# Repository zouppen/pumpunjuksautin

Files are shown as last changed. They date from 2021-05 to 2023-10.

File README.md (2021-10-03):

# Pumpunjuksautin - Defrauding heat pumps for fun and profit

## Introduction
Pumpunjuksautin is a device for introducing a measure of load control into
heating systems where no external control features such as automation buses
exist. The core idea is to modify the signal the heating controller gets from
the thermistor measuring it's warm water accumulator temperature. By modifying
this signal so that the accumulator seems warmer than it is in actuality, the
heating can be impeded until the desired time.

In practice, Pumpunjuksautin is meant to be attached to Modbus RTU bus, through
which it is controlled by building automation. Typically the heating duty cycle
is delayed until either energy market or solar power generation allow for cost
efficient heating.

## Repository content
This repository contains the design of the whole Pumpunjuksautin device,
divided to it's components:
* [Firmware source code](avr/)
* [Documentation](docs/)
* [Enclosure design](enclosure/README.md)
* [Printed circuit board design](pcb/)
* [Operational utilities](juksutil/) (JuksUtil)

## License
The contents of this repository are licensed under the GNU General Public
License version 3 or later. See file LICENSE for the license text.

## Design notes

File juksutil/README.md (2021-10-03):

# JuksUtil

Utility for communicating with JuksOS devices, including
Pumpunjuksautin. Supports both ASCII and Modbus protocols.

## Compiling

Requires a C compiler, libmodbus and glib libraries and CMake to build. In Debian
and Ubuntu, you can install the requirements with:

```sh
sudo apt install cmake libmodbus-dev libglib2.0-dev
```

To build:

```sh
mkdir build
cd build
cmake ..
make
```

## Summary of commands

In principle, if when using ASCII interface, you must supply device
path with `-d`. With Modbus, you additionally need server id (better
known as slave id) with `-s`.

Time zone related commands such as `show-transition` and `sync-time`
accept `-z` parameter for supplying the desired time zone.

Help is available with `juksutil --help`.

### show-transition

Show current time zone and future DST transition, if any. Doesn't need
any device. It just shows what would be written. Also, it's
suprisingly useful tool to check DST changes overall, in case you are
interested about time zone stuff like me.

<pre>
$ juksutil show-transition
Current and following time zone for <strong>Europe/Berlin</strong>:

                  <strong>UTC time             Local time           Zone   UNIX time  UTC off
Current time:</strong>     2021-10-03 18:59:09  2021-10-03 20:59:09  +0200  1633287549   +7200
<strong>Next transition:</strong>  2021-10-31 01:00:00  2021-10-31 02:00:00  +0100  1635642000   +3600

That is, on October 31 when the time gets 03:00, the hands are moved to 02:00.
</pre>

### get-time

Get current time from the device. Format is ISO 8601 timestamp with
time zone. It shows the current time and time zone the device is
observing.

### sync-time

Synchronize clock of JuksOS device. Sets also DST transition
table. Supply the desired time zone with `-z` or otherwise your
computer zone is used.

The command outputs nothing on success. To verify it, you may run
`juksutil get-time`.

### send

Read and/or write values from/to the hardware via ASCII
interface. This requires that the device firmware is built with ASCII
interface (CMake variable `-D WITH_ASCII=ON`).

The format is: `send KEY[=VALUE]..`, example: `juksutil send version led=1`.

The supported commands are described in [commands.tsv](../avr/commands.tsv).

## How about supporting the remaining Modbus commands?

Not all Modbus commands are supported because there is better tools for
doing the stuff which are not timing critical like setting clock
time. One of them is a nice command-line utility called
[modbus-cli](https://github.com/favalex/modbus-cli).

Modbus register chart is available in [commands.tsv](../avr/commands.tsv).

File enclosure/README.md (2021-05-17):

# Enclosure

Enclosure for Pumpunjuksautin. Designed for DIN rail attachment

## Copyright

PCB mounting clip for 35mm DIN Rail (file din_clip_01.dxf) by
RobertHuntis licensed under the Creative Commons - Attribution
license. Fetched from https://www.thingiverse.com/thing:101024

Rest is work by Joel Lehtonen.

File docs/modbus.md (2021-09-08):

# Modbus register table

**THIS IS A DRAFT!**

## Coils

Coils are read-write.

|  Address | False | True | Description |
|---:|---|---|---|
| `0x0001` | LED off | LED on | Indicator LED control (for testing comms) |

## Input bits

Every input is read-only.

|  Address | False | True | Description |
|---:|---|---|---|
| `0x0001` | LED off | LED on | Heat pump error LED status |
| `0x0002` | Clock unset | Clock set | Internal real-time clock status |

## Holding registers

A single register is 16-bit value. All values spanning multiple
registers have big-endian byte order.

| Address | Size | Read | Write | Data type | Unit | Description |
|---|-----:|:----:|:-----:|---|---|---|
| TBD | 16 | X | | char[32]  | | Firmware version string, NUL padded |
| TBD | 2 | X | X | uint32 | unix | Current system time |
| TBD | 2 | X | X | int32 | gmtoff | Current UTC offset |
| TBD | 2 | X | X | uint32 | unix | Time of next UTC offset change. 0 if not set. |
| TBD | 2 | X | X | int32 | gmtoff | Next UTC offset |
| TBD | 1 | X | | int16 | 0.01°C | Heat pump temperature (K9 thermistor line) |
| TBD | 1 | X | | int16 | 0.01°C | Tank temperature (K5 thermistor line) |
| TBD | 1 | X | | int16 | 0.01°C | Outside temperature |
| TBD | 1 | X | X | int16 | mV | Juksautus target voltage |
| TBD | 1 | X | | int16 | mV | Juksautus measured voltage |

## Legend

* **size**: Data length in number of registers (`nb` in libmodbus)
* **unix**: Number of seconds since UNIX epoch
* **gmtoff**: UTC offset in seconds

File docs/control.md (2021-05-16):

# How Pumpunjuksautin works

Pulls voltage over NTC thermistor while recovering original thermistor
resistance.

The firmware has bookkeeping about the duty cycle. For example if the
*DRIVE* is in LOW state for 10 ms and in HI-Z state for 90 ms, the duty
cycle D is 0.9.

Fill in parameters in this formula from the circuit below:



Variables in the formula

This allows us to fake a higher temperature reading and at the same time
do measurements. All this without disconnecting the thermistor from the
circuit.

## Is it possible to fake lower temperatures, too?

Yes, but the formulas aren't derived yet... We can put *DRIVE* to 5
volts and observe the duty cycle.

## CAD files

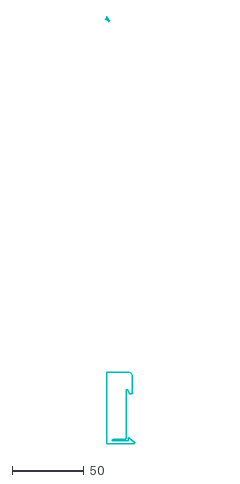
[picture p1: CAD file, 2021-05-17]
enclosure/din_clip_01.dxf
20.4 x 298.3

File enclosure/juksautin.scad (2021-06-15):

open = true;
//open = false;

module screwdriver_hole(width, length, depth) {
    linear_extrude(depth) {
        // The screwdriver opening
        hull() {
            for (pos = [-length/2, length/2]) {
                translate([pos,0,0]) circle(width/2, $fn=6);
            }
        }
    }
}

// Din rail clamp
difference() {
    pos_x = pcb_width/2-19;
    pos_y = h+2;
    linear_extrude(inner_height+2) translate([pos_x,pos_y,0]) rotate([180,0,90]) import("din_clip_01.dxf");
    translate([pos_x,pos_y+12.6,inner_height/2+1]) rotate([0,90,0]) screwdriver_hole(2, 5, 3);
}

translate([2+margin/2,2+margin/2 + (open ? -60 : 0),pcb+pcb_surface]) {
    // Kicad model via Blender
    rotate([90,0,0]) translate([0,0,0]) import("pcb.stl");
}

module pcb_box(w, h, pcb_thickness, above, below, rail=3, wall=2) {
    inside_h = above+below+pcb_thickness;
    difference () {
        // Outer wall
        cube([w+2*wall, h+2*wall, inside_h+2*wall]);
        // Inner wall
        translate([wall+rail,0,wall]) {
            cube([w-2*rail, h+wall, inside_h]);
        }
        // Rail
        translate([wall,wall-1,wall+below]) {
            cube([w,h+1, pcb_thickness]);
        }
        // Front opening
        translate([wall,0,wall]) {
            cube([w,wall,inside_h]);
        }
        
        // Half a wall from the front. +1 offset to avoid UI bug.
        translate([-1,-1,-1]) cube([w+2*wall+2,wall/2+1,inside_h+2*wall+2]);
        
        dent_depth=3;
        translate([wall,2*wall, wall+below+pcb_thickness-margin]) {
            cube([w,dent_depth,above+margin]);
        }
    }
}

module mc(x,z,terminals=9, pitch=3.81) {
    translate([x-margin/2,-1,z-margin/2]) cube([5.2+(terminals-1)*pitch+margin,4,7.25+margin]);
}

margin = 0.4;
pcb = 1.6;
pcb_real = 2.2;
pcb_width = 65+margin;
h = 35+margin;
pcb_surface = 3.5;
pull = 3;

thick = 2+1.2; // Thickness of front panel

module clip() {
    clip_start = 4.4;
    clip_x = 1.5;
    clip_y = 3.9;
    clip_w = 2.4;
    clip_h = 7;
    clip_z = 7.85;
    translate([0,0,clip_z]) linear_extrude(clip_h) polygon([[0,0],[clip_w,0],[clip_w,clip_start+clip_y],[-clip_x,clip_start],[0,clip_start]]);
}

above=12;

// PCB box
pcb_box(pcb_width, h, pcb_real, above-pcb+margin, pcb_surface-pcb, rail=1.5);

// Calculated from magic values
inner_height = pcb_real+ above-pcb+margin+pcb_surface-pcb+2;

translate([open ? 80 : 0,0,0]) with_idc_frame([49.25,0,pcb_surface+0.8],8) {
    difference () {
        union () {
            // Outer cover
            cube([pcb_width+4,1,inner_height+2]);

            // Indent
            translate([2+margin/2,1,2+margin/2]) {
                cube([pcb_width-margin,1,inner_height-margin-2]);
            }
            
            // Clips
            translate([4-0.2,0,0]) clip();
            translate([pcb_width+0.2,0,0]) mirror([1,0,0]) clip();

        }
        
        mc(8.1,pcb_surface+2.4);
    }
}

module with_idc_frame(pos=[0,0,0], depth=5) {
    module obj(tweak=0) {
        translate(pos) rotate([90,0,0]) translate([0,-20,-depth-tweak]) linear_extrude(depth+2*tweak) children();
    }
    
    difference() {
        children();
        obj(0.1) import("idc-inner.svg");
    }
    obj() import("idc-outer.svg");
}

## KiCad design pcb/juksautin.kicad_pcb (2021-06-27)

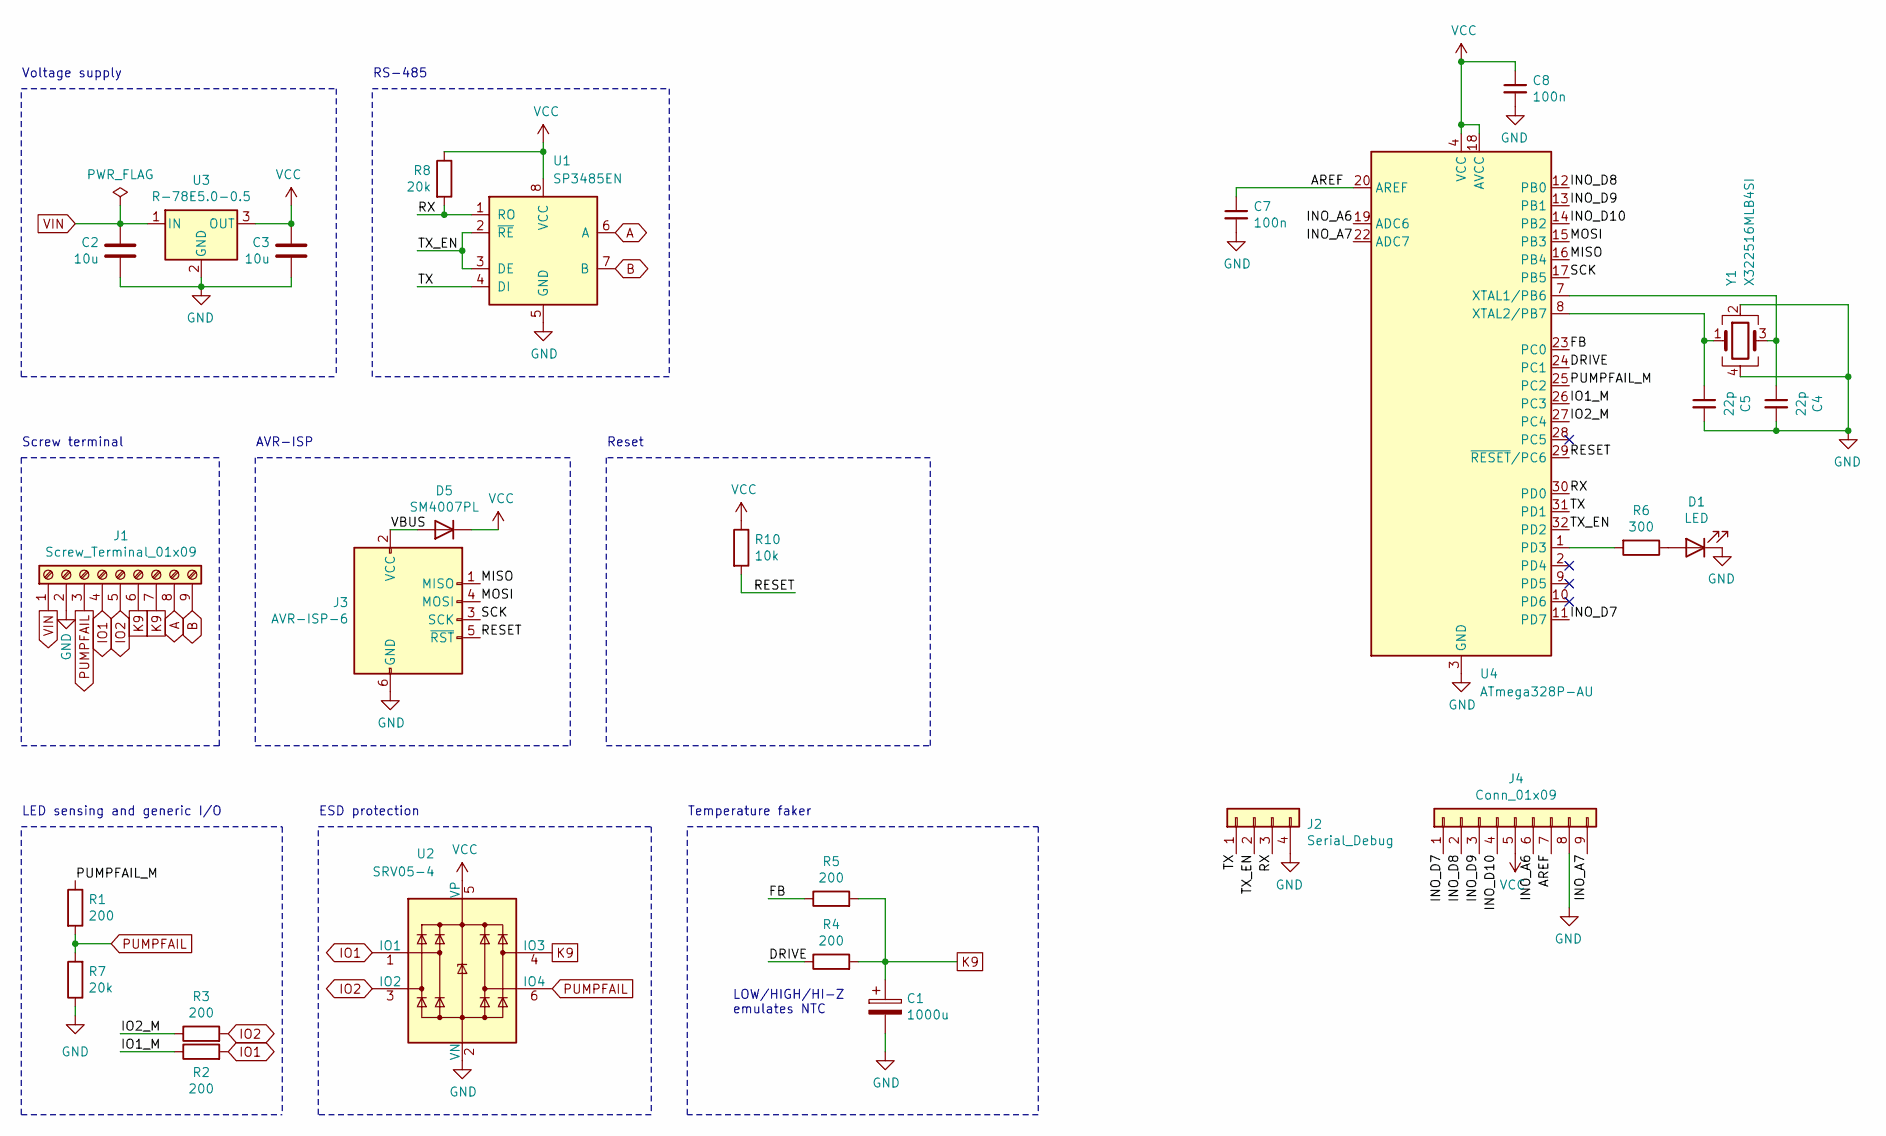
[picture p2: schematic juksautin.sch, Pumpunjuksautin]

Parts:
C1: 1000u; CP_Elec_8x10; LCSC C134755
C2, C3: 10u; C_1206_3216Metric; LCSC C13585
C4, C5: 22p; C_0402_1005Metric; LCSC C1555
C7, C8: 100n; C_0402_1005Metric; LCSC C1525
D1: LED; LED_0603_1608Metric; LCSC C72043
D5: SM4007PL; D_SOD-123F; LCSC C64898
J1: Screw_Terminal_01x09; PhoenixContact_MC_1,5_9-G-3.81_1x09_P3.81mm_Horizontal
J2: Serial_Debug; PinHeader_1x04_P1.27mm_Vertical
J3: AVR-ISP-6; PinHeader_2x03_P2.54mm_Horizontal
J4: Conn_01x09; PinHeader_1x09_P2.54mm_Vertical
R1, R2, R3, R4, R5: 200; R_0603_1608Metric; LCSC C8218
R6: 300; R_0603_1608Metric; LCSC C23025
R7, R8: 20k; R_0603_1608Metric; LCSC C4184
R10: 10k; R_0603_1608Metric; LCSC C25804
U1: SP3485EN; SOIC-8_3.9x4.9mm_P1.27mm; LCSC C8963
U2: SRV05-4; SOT-23-6; LCSC C85364
U3: R-78E5.0-0.5; Converter_DCDC_RECOM_R-78E-0.5_THT
U4: ATmega328P-AU; TQFP-32_7x7mm_P0.8mm
Y1: X322516MLB4SI; Crystal_SMD_3225-4Pin_3.2x2.5mm

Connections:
/AREF: C7.1, J4.7, U4.20 (AREF)
/DRIVE: R4.1, U4.24 (PC1)
/FB: R5.1, U4.23 (PC0)
/INO_A6: J4.6, U4.19 (ADC6)
/INO_A7: J4.9, U4.22 (ADC7)
/INO_D7: J4.1, U4.11 (PD7)
/INO_D8: J4.2, U4.12 (PB0)
/INO_D9: J4.3, U4.13 (PB1)
/INO_D10: J4.4, U4.14 (PB2)
/IO1_M: R2.1, U4.26 (PC3)
/IO2_M: R3.1, U4.27 (PC4)
/MISO: J3.1 (MISO), U4.16 (PB4)
/MOSI: J3.4 (MOSI), U4.15 (PB3)
/PUMPFAIL_M: R1.1, U4.25 (PC2)
/RESET: J3.5 (~RST), R10.2, U4.29 (~RESET~/PC6)
/RX: J2.3, R8.2, U1.1 (RO), U4.30 (PD0)
/SCK: J3.3 (SCK), U4.17 (PB5)
/TX: J2.1, U1.4 (DI), U4.31 (PD1)
/TX_EN: J2.2, U1.2 (~RE~), U1.3 (DE), U4.32 (PD2)
/VBUS: D5.2 (A), J3.2 (VCC)
A: J1.8, U1.6 (A)
B: J1.9, U1.7 (B)
GND: C1.2, C2.2, C3.2, C4.2, C5.2, C7.2, C8.2, D1.1 (K), J1.2, J2.4, J3.6 (GND), J4.8, R7.1, U1.5 (GND), U2.2 (VN), U3.2 (GND), U4.3 (GND), U4.5 (GND), U4.21 (GND), Y1.2, Y1.4
IO1: J1.4, R2.2, U2.1 (IO1)
IO2: J1.5, R3.2, U2.3 (IO2)
K9: C1.1, J1.6, J1.7, R4.2, R5.2, U2.4 (IO3)
unnamed: C4.1, U4.7 (XTAL1/PB6), Y1.3
unnamed: C5.1, U4.8 (XTAL2/PB7), Y1.1
unnamed: D1.2 (A), R6.1
unnamed: R6.2, U4.1 (PD3)
PUMPFAIL: J1.3, R1.2, R7.2, U2.6 (IO4)
VCC: C3.1, C8.1, D5.1 (K), J4.5, R8.1, R10.1, U1.8 (VCC), U2.5 (VP), U3.3 (OUT), U4.4 (VCC), U4.6 (VCC), U4.18 (AVCC)
VIN: C2.1, J1.1, U3.1 (IN)

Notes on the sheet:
LOW/HIGH/HI-Z emulates NTC
LED sensing and generic I/O
Temperature faker
Screw terminal
RS-485
Voltage supply
ESD protection
AVR-ISP
Reset

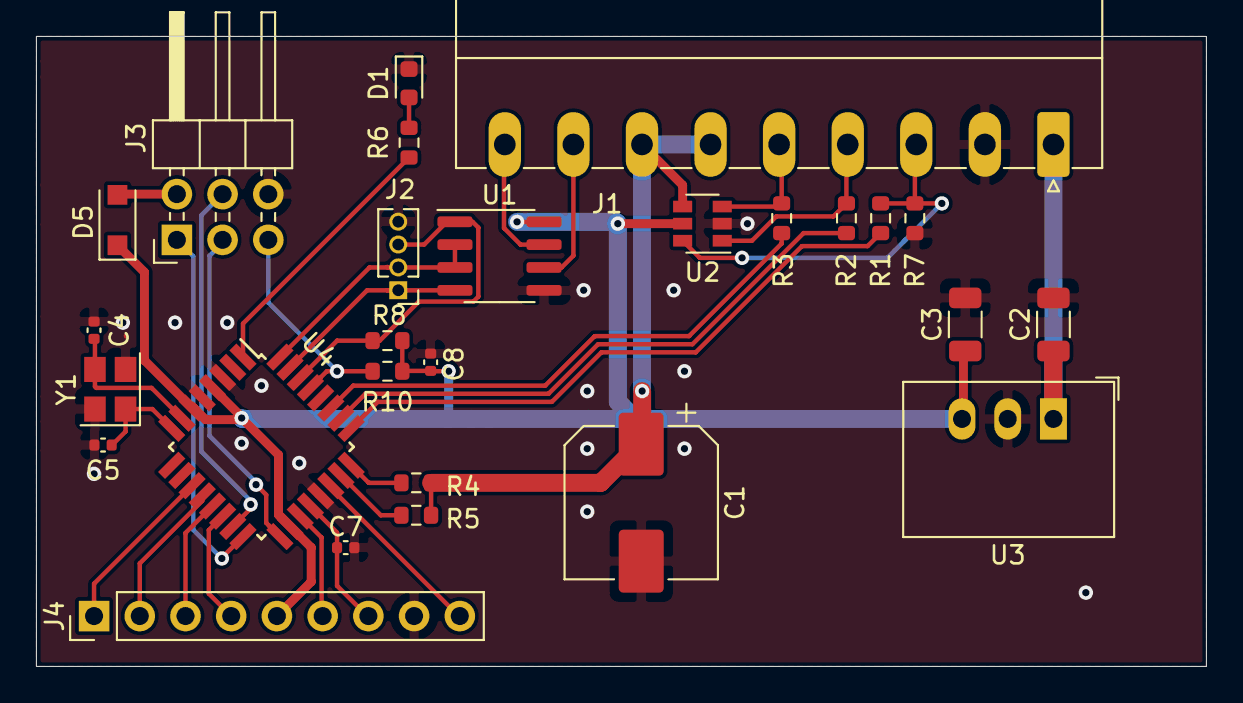
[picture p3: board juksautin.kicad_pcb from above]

Board: 2 copper layers, 65.0 x 35.0 mm, 27 parts (0 on the bottom side), 33 nets.

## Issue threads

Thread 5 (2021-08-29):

ASCII protocol

zouppen, 2021-08-29:
Implement serial line protocol in plain ASCII which doesn't clash with Modbus #16 so in theory they could be simultaneously enabled. This makes controlling the device easier with plain socat.

zouppen, 2021-09-11:
I consider the protocol done. It doesn't yet have so many commands but the architecture is proven so the rest is just adding more and more commands,

Closed 2021-09-11.

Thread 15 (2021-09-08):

Output gets sometimes trucated in process_write() in interface_ascii.c

zouppen, 2021-09-08:
Currently using format string `%1s` instead of `%s` because for some reason the output is truncated with input of
"`WRITE`". Doesn't happen with "`WRITE `". This might be avr-libc bug or a memory leak in our code.

Doesn't help if using SRAM strings instead of PROGMEM.

zouppen, 2021-09-08:
NULL pointer was printed with %s which caused the formatting issue. Checking NULL condition before calling the function.

Closed 2021-09-08.

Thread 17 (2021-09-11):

Use fixed point where practical

zouppen, 2021-09-11:
Get rid of unnecessary floating point operations both for speed reasons but more importantly for making the control logic more accurate because Modbus #16 anyway will use millivolts in the control

zouppen, 2021-09-20:
Git grep tells me all floating point operations except `juksautin_compute_k5_real_voltage` are removed. That function is not currently called from anywhere. Consider this done.

Closed 2021-09-20.

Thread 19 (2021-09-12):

EEPROM storage

zouppen, 2021-09-12:
Use EEPROM storage for some configuration variables to make them persistent over boot, such as:

- Juksautus target voltage
- Temperature conversion coefficients
- Time zone information

zouppen, 2021-09-20:
This is done, also added fuse change to allow EEPROM to stay intact after firmware updates. There is #22 which will go to EEPROM, too, but it's a separate ticket. Temperature coefficients are different case, too, related to #3. Done.

Closed 2021-09-20.

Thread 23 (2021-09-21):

Clock drift correction

zouppen, 2021-09-21:
There is external and decent 16MHz crystal on board but it could be made more accurate, especially when Juksautin is having constant temperature conditions. It requires three facilities:

* [ ] EEPROM or SRAM storage of last written timestamp
* [ ] Holding register for clock drift (int32)
* [ ] System tick change: Add countdown for the next adjustment
* [ ] Utility for updating the clock while adjusting drift

Low priority. Nice to have.

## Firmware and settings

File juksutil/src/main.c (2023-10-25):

// Main module for JuksUtil
// SPDX-License-Identifier:   GPL-3.0-or-later
// Copyright (C) 2021 Joel Lehtonen
//
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
#define _GNU_SOURCE
#include <stdio.h>
#include <stdlib.h>
#include <unistd.h>
#include <modbus.h>
#include <err.h>
#include <errno.h>
#include <glib.h>
#include <time.h>
#include <inttypes.h>
#include "tz.h"
#include "sync_clock.h"
#include "serial.h"

static time_t get_timestamp(void);
static tzinfo_t get_tzinfo(void);
static char *format_iso8601(time_t ref);
static char *format_localtime(time_t ref, int32_t gmtoff, char *fmt);
static void cmd_show_transition(void);
static void cmd_sync_clock_modbus();
static void cmd_sync_clock_ascii();
static void cmd_get_time_modbus();
static void cmd_get_time_ascii();
static void cmd_ascii(int const argc, char **argv);
static bool matches(char const *const arg, char const *command, bool const cond);
static void serial_timeout(int signo);
static modbus_t *main_modbus_init(void);
static void main_modbus_free(modbus_t *ctx);
static FILE *main_serial_init(void);

static gchar *time_zone = "localtime";
static gchar *now_str = NULL;
static gchar *dev_path = NULL;
static gint dev_baud = 9600;
static gint dev_slave = 0;
static gboolean break_first = false;

static GOptionEntry entries[] =
{
	{ "timezone", 'z', 0, G_OPTION_ARG_STRING, &time_zone, "Time zone used in date operations, e.g. Europe/Berlin. Default: localtime", "TZ"},
	{ "now", 'n', 0, G_OPTION_ARG_STRING, &now_str, "Use this time instead of current time. Any format accepted by `date` is fine. Default: now", "STRING"},
	{ "device", 'd', 0, G_OPTION_ARG_FILENAME, &dev_path, "Device path to JuksOS device", "PATH"},
	{ "baud", 'b', 0, G_OPTION_ARG_INT, &dev_baud, "Device baud rate. Default: 9600", "BAUD"},
	{ "slave", 's', 0, G_OPTION_ARG_INT, &dev_slave, "Device Modbus server id. If not defined, ASCII protocol is used", "ID"},
	{ "break", 'B', 0, G_OPTION_ARG_NONE, &break_first, "Send BREAK before the command. Default: no break", NULL},
	{ NULL }
};

int main(int argc, char **argv)
{
	g_autoptr(GError) error = NULL;
	g_autoptr(GOptionContext) context = g_option_context_new("COMMAND");
	g_option_context_add_main_entries(context, entries, NULL);
	g_option_context_set_summary(context, "Tool for communicating with JuksOS devices such as Pumpunjuksautin.");
	g_option_context_set_description(context,
					 "Commands:\n"
					 "  show-transition       Show current time zone and future DST transition, if any.\n"
					 "  get-time              Get current time from the device.\n"
					 "  sync-time             Synchronize clock of JuksOS device. Sets also DST transition table.\n"
					 "  send KEY[=VALUE]..    Read and/or write values from/to the hardware via ASCII interface\n"
					 "\n"
					 "For more information about accepted timestamp formats, run: info coreutils date input\n"
					 "To get list of all time zones known by your system, run: timedatectl list-timezones\n"
					 "");

	if (!g_option_context_parse(context, &argc, &argv, &error))
	{
		errx(1, "Option parsing failed: %s", error->message);
	}

	// Command validation and selection
	if (argc < 2) {
		errx(1, "Command missing. See %s --help", argv[0]);
	}

	// Set up signal handler for timeouts
	struct sigaction act;
	act.sa_handler = serial_timeout;
	sigemptyset(&act.sa_mask);
	act.sa_flags = 0;
	if (sigaction(SIGALRM, &act, NULL) == -1) {
		err(1, "Unable to set a signal handler");
	}

	// Command parser
	if (matches(argv[1], "show-transition", argc == 2)) {
		// Validate args
		cmd_show_transition();
	} else if (matches(argv[1], "sync-time", argc == 2)) {
		if (dev_slave) {
			cmd_sync_clock_modbus();
		} else {
			cmd_sync_clock_ascii();
		}
	} else if (matches(argv[1], "get-time", argc == 2)) {
		if (dev_slave) {
			cmd_get_time_modbus();
		} else {
			cmd_get_time_ascii();
		}
	} else if (matches(argv[1], "send", argc > 2)) {
		cmd_ascii(argc-2, argv+2);
	} else {
		errx(1, "Invalid command name. See %s --help", argv[0]);
	}
	return 0;
}

static bool matches(char const *const arg, char const *command, bool const cond)
{
	if (strcmp(arg, command)) return false;
	if (!cond) errx(1, "Invalid number of arguments to %s. See --help", command);
	return true;
}

static void cmd_ascii(int const cmds, char **cmd)
{
	if (dev_slave) {
		errx(1, "ASCII interface not available using Modbus. Don't use -s.");
	}
	
	// Craft compound message
	g_autoptr(GString) line_in = g_string_new(cmd[0]);
	for (int i=1; i<cmds; i++) {
		g_string_append_c(line_in, ' ');
		g_string_append(line_in, cmd[i]);
	}
	g_string_append_c(line_in, '\n');

	// Do the serial operations with a timeout
	alarm(1);

	FILE *f = main_serial_init();

	if (fputs(line_in->str, f) == EOF) {
		errx(1, "Unable to write to serial port");
	}

	char *line_out = NULL;
	size_t len = 0;
	if (getline(&line_out, &len, f) == -1) {
		errx(1, "Unable to read from serial port");
	}

	// Cancel timeout
	alarm(0);

	if (line_out[0] == ' ') {
		// Put the command as a reference for the error
		// message.
		fputs(line_in->str, stdout);
	}
	fputs(line_out, stdout);
	free(line_out);
	fclose(f);
}

static void serial_timeout(int signo) {
	errx(1, "ASCII serial protocol timeout. Is the device on and is the baud rate correct?");
}

// Command for getting current time via ASCII
static void cmd_get_time_ascii()
{
	char *s = "now";
	cmd_ascii(1, &s);
}

// Command for getting current time via Modbus
static void cmd_get_time_modbus()
{
	modbus_t *ctx = main_modbus_init();
	
	g_autoptr(GString) s = g_string_new(NULL);
	sync_clock_get_time_modbus(s, ctx);
	puts(s->str);

	main_modbus_free(ctx);
}

// Command for syncing the clock time of a device.
static void cmd_sync_clock_modbus()
{
	modbus_t *ctx = main_modbus_init();
	
	tzinfo_t info = get_tzinfo();
	sync_clock_modbus(&info, now_str == NULL, ctx);

	main_modbus_free(ctx);
}

// Command for syncing the clock time of a device.
static void cmd_sync_clock_ascii()
{
	FILE *f = main_serial_init();

	tzinfo_t info = get_tzinfo();
	sync_clock_ascii(&info, now_str == NULL, f);

	fclose(f);
}

// Command for just showing the next DST transition and the UTC offset
// before and after the transition.
static void cmd_show_transition()
{
	tzinfo_t info = get_tzinfo();
	char *reftime_label = now_str == NULL ?
		"Current time:  ":
		"Reference time:";
	g_autoptr(GString) name = tz_name(time_zone);
	printf("Current and following time zone for \x1b[1m%s\x1b[0m:\n\n", name->str);
	printf("\x1b[1m                  UTC time             Local time           Zone   UNIX time  UTC off\x1b[0m\n");
	printf("\x1b[1m%s\x1b[0m   %-21s%-27s%11ld%+8d\n", reftime_label, format_iso8601(info.ref_time), format_localtime(info.ref_time, info.gmtoff_now, "%F %T  %z"), info.ref_time, info.gmtoff_now);
	if (info.transition) {
		printf("\x1b[1mNext transition:\x1b[0m  %-21s%-27s%11ld%+8d\n", format_iso8601(info.transition), format_localtime(info.transition, info.gmtoff_after, "%F %T  %z"), info.transition, info.gmtoff_after);
		printf("\nThat is, on %s,", format_localtime(info.transition, info.gmtoff_now, "%B %d when the time gets %H:%M"));
		printf(" the hands are moved to %s.\n", format_localtime(info.transition, info.gmtoff_after, "%H:%M"));
	} else {
		printf("\x1b[1mNext transition:\x1b[0m  No future transitions\n");
	}
}

// Returns time formatted to ISO 8601 UTC timestamp. This function is
// not re-entrant. May terminate the program in case of an error.
static char *format_iso8601(time_t ref)
{
	static char buf[25];
	struct tm *tm = gmtime(&ref);
	if (tm == NULL) goto fail;
	if (strftime(buf, sizeof(buf), "%F %T", tm) == 0) goto fail;
	return buf;
 fail:
	errx(1, "Date formatting error");
}

// Returns time formatted to ISO 8601 local time. This function is
// not re-entrant. May terminate the program in case of an error.
static char *format_localtime(time_t ref, int32_t gmtoff, char *fmt)
{
	static char buf[40];
	ref += gmtoff;
	struct tm tm;
	gmtime_r(&ref, &tm);
	tm.tm_gmtoff = gmtoff; // glibc only way to set timezone!
	if (strftime(buf, sizeof(buf), fmt, &tm) == 0) goto fail;
	return buf;
 fail:
	errx(1, "Date formatting error");
}

// Get timestamp from global variable if set or use the current
// time. May terminate the program if invalid time given.
static time_t get_timestamp()
{
	time_t now;

	// Fetching current time
	if (now_str != NULL) {
		// Trying to parse it to UNIX timestamp with
		// `date`. It's better than any libc or glib
		// parsing function.
		g_autoptr(GString) cmd = g_string_new("date +%s -d");
		gchar *quoted = g_shell_quote(now_str);
		g_string_append(cmd, quoted);
		g_free(quoted);
		FILE *f = popen(cmd->str, "r");
		if (f == NULL) {
			err(1, "Unable to run date command");
		}
		int matches = fscanf(f, "%" SCNu64, &now);
		pclose(f);
		if (matches != 1) {
			// The error message is printed anyway by date
			exit(1);
		}
	} else {
		now = time(NULL);
	}
	if (now == -1) {
		errx(1, "Fatal date error");
	}
	return now;
}

// Get time zone information based on global variables. May terminate
// the program if invalid time or zone given.
tzinfo_t get_tzinfo()
{
	tzinfo_t info;
	if (!tz_populate_tzinfo(&info, time_zone, get_timestamp())) {
		err(1, "tzinfo reading failed");
	}
	return info;
}

static modbus_t *main_modbus_init(void)
{
	if (dev_path == NULL) {
		errx(1, "Device name must be given with -d, optionally baud rate with -b and server id with -s");
	}

	if (break_first) {
		FILE *f = serial_fopen(dev_path, dev_baud, true);
		if (f == NULL || fclose(f)) {
			err(1, "Unable to send break signal");
		}
	}

	// Prepare modbus
	modbus_t *ctx = modbus_new_rtu(dev_path, dev_baud, 'N', 8, 1);
	if (ctx == NULL) {
		goto modbus_error;
	}

	if (modbus_connect(ctx)) {
		goto modbus_error;
	}

	if (modbus_set_slave(ctx, dev_slave)) {
		goto modbus_error;
	}
	
	return ctx;
 modbus_error:
	errx(5, "Modbus communication error: %s", strerror(errno));
}

static void main_modbus_free(modbus_t *ctx)
{
	modbus_close(ctx);
	modbus_free(ctx);
}

static FILE *main_serial_init(void)
{
	if (dev_path == NULL) {
		errx(1, "Device name must be given with -d, optionally baud rate with -b");
	}

	// Serial comms
	FILE *f = serial_fopen(dev_path, dev_baud, break_first);
	if (f == NULL) {
		err(1, "Unable to open serial port");
	}

	return f;
}

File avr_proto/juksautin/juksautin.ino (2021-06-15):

// Pumpunjuksautin prototype for ATMega328p

// Note, many macro values are defined in <avr/io.h> and
// <avr/interrupts.h>, which are included automatically by
// the Arduino interface

#include <stdio.h>
#include <string.h>
#include <stdbool.h>
#include <util/atomic.h>
#include "pin.h"

// Store analog measurement sum and measurement count. Used for mean
// calculation.
typedef struct {
	uint32_t sum;
	uint16_t count;
} accu_t;

// Struct of accumulators.
typedef struct {
	accu_t k9_raw;    // Real voltage in K9
	accu_t int_temp;  // AVR internal temperature
	accu_t juksautin; // Juksautin ratio
} accus_t;

// Prototypes
inline void store(volatile accu_t *a, uint16_t val);
void serial_flush(void);

#define VOLT (1.1f / 1024) // 1.1V AREF and 10-bit accuracy
#define PIN_FB C,1
#define SERIAL_BUF_LEN 40

volatile accus_t v_accu; // Holds all volatile measurement data
volatile uint16_t target; // Target voltage for juksautus
char serial_buf[SERIAL_BUF_LEN]; // Outgoing serial data
volatile int serial_tx_i = 0; // Send buffer position

// Set ADC source. Do not set above 15 because then you will overrun
// other parts of ADMUX. A full list of possible inputs is available
// in Table 24-4 of the ATMega328 datasheet.
void start_adc_sourcing(uint8_t chan) {
	ATOMIC_BLOCK(ATOMIC_RESTORESTATE) {
		// Clear MUX3..0 in ADMUX (0x7C) in preparation for setting the analog
		// input
		ADMUX &= 0b11110000;

		// Set MUX3..0 in ADMUX (0x7C) to select ADC input
		ADMUX |= chan;

		// Set ADSC in ADCSRA (0x7A) to start the ADC conversion
		ADCSRA |= 0b01000000;
	}
}

// Set juksautin target voltage.
void set_voltage(float u) {
	uint16_t new_target = u / 1.1 * 1024;
	ATOMIC_BLOCK(ATOMIC_RESTORESTATE) {
		target = new_target;
	}
}

// Initialization
void setup() {
	// Serial port setup
	Serial.begin(9600);
	while (!Serial) {
		// wait for serial port to connect. Needed for native USB port only
	}

	UCSR0B |= (1<<TXCIE0); // transmit ready interrupt

	set_voltage(0.5);

	// ADC setup

	// clear ADLAR in ADMUX (0x7C) to right-adjust the result
	// ADCL will contain lower 8 bits, ADCH upper 2 (in last two bits)
	ADMUX &= 0b11011111;

	// Set REFS1..0 in ADMUX (0x7C) to change reference voltage to internal
	// 1.1V reference
	ADMUX |= 0b11000000;

	// Set ADEN in ADCSRA (0x7A) to enable the ADC.
	// Note, this instruction takes 12 ADC clocks to execute
	ADCSRA |= 0b10000000;

	// Clear ADTS2..0 in ADCSRB (0x7B) to set trigger mode to free running.
	// This means that as soon as an ADC has finished, the next will be
	// immediately started.
	ADCSRB &= 0b11111000;

	// Set the Prescaler to 128 (16000KHz/128 = 125KHz)
	// Above 200KHz 10-bit results are not reliable.
	ADCSRA |= 0b00000111;

	// Set ADIE in ADCSRA (0x7A) to enable the ADC interrupt.
	// Without this, the internal interrupt will not trigger.
	ADCSRA |= 0b00001000;

	// Enable global interrupts
	// AVR macro included in <avr/interrupts.h>, which the Arduino IDE
	// supplies by default.
	sei();

	// Set ADSC in ADCSRA (0x7A) to start the ADC conversion
	start_adc_sourcing(8);

	// Set FB pin as input
	LOW(PIN_FB);
	INPUT(PIN_FB);
}

// Take analog accumulator mean value
float accu_mean(accu_t *a) {
	return (float)a->sum / a->count;
}

// Processor loop
void loop() {
	static uint16_t i = ~0;

	// Come here only after serial comms is finished.
	int writing;
	ATOMIC_BLOCK(ATOMIC_FORCEON) {
		writing = serial_tx_i;
	}
	if (writing) return;
	i++;

	// Duplicate the data
	accus_t accu;
	ATOMIC_BLOCK(ATOMIC_FORCEON) {
		// The buffer is so small it makes more sense to use copying than
		// front/back buffering at the moment.
#pragma GCC diagnostic ignored "-Wdiscarded-qualifiers"
		// We are safely fiddling with volatile, so we just
		// turn off warnings at this stage.
		memcpy(&accu, &v_accu, sizeof(accu));
		memset(&v_accu, 0, sizeof(v_accu));
#pragma GCC diagnostic pop
	}

	float ratio = accu_mean(&accu.juksautin);
	float int_temp = (accu_mean(&accu.int_temp)-324.31)/1.22;
	float k9_raw = accu_mean(&accu.k9_raw) * VOLT;

	int wrote = snprintf(serial_buf, SERIAL_BUF_LEN, "%" PRIu16 ": %d°C %dmV %d%% %" PRIu16 "\n", i, (int)int_temp, (int)(k9_raw*1000), (int)(ratio*100), accu.juksautin.count);
	
	if (wrote >= SERIAL_BUF_LEN) {
		// Ensuring endline in the end
		serial_buf[SERIAL_BUF_LEN-2] = '\n';
		serial_buf[SERIAL_BUF_LEN-1] = '\0';
	}
	serial_flush();

	// Quick hack
	if (Serial.available() > 0) {
		float target = Serial.parseFloat();
		while (Serial.read() != '\n');
		set_voltage(target);
	}

	// Whatever else you would normally have running in loop().
}

// Interrupt service routine for the ADC completion
ISR(ADC_vect) {
	static bool juksautus = false;
	// Store the ADC port of previous measurement before changing it
	uint8_t port = ADMUX & 0b00001111;

	// Start the next measurement ASAP to minimize drift caused by this ISR.
	// Rotate between different analog inputs.
	uint8_t cycle = v_accu.juksautin.count & 0b111; // Cycle length: 8
	switch (cycle) {
	case 0:
		// Internal temperature measurement
		start_adc_sourcing(8);
		break;
	default:
		// NTC thermistor measurement
		start_adc_sourcing(0);
		break;
	}

	// Obtain previous result.
	uint16_t val = ADCW;

	switch (port) {
	case 0:
		// Pump logic. Pull capacitor down to target voltage.
		juksautus = val > target;
		if (juksautus) {
			OUTPUT(PIN_FB);
		} else {
			INPUT(PIN_FB);
		}

		// Store measurement
		store(&v_accu.k9_raw, val);

		break;
	case 8:
		store(&v_accu.int_temp, val);
		break;
	}

	// What we really are interested is the ratio of pulldowns and total measurements.
	// That allows us to calculate the real thermistor value while juksautus is happening.
	// We calculate juksautus count by counting the periods of time the current is flowing.
	store(&v_accu.juksautin, juksautus);
}

// Update cumulative analog value for access outside the ISR. Do not let it overflow.
inline void store(volatile accu_t *a, uint16_t val) {
	// Stop storing when full
	if (a->count == ~0) return;
	a->sum += val;
	a->count++;
}

void serial_flush(void) {
	ATOMIC_BLOCK(ATOMIC_FORCEON) {
		UDR0 = serial_buf[0];
		serial_tx_i = 1;
	}
}

ISR(USART_TX_vect)
{
	// Don't go further if it has been already sent
	if (serial_tx_i == 0) return;

	char out = serial_buf[serial_tx_i];
	UDR0 = out;

	// Stop at NUL char
	if (out == '\0') {
		serial_tx_i = 0;
	} else {
		serial_tx_i++;
	}
}

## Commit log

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2021-05-17 Old version of the enclosure
    [juksautin.scad]
2021-05-17 Din rail enclosure
    [din_clip_01.dxf, juksautin.scad]
2021-05-17 Make it even smaller to fit a narrow spot in DIN rail
    [juksautin.scad]
2021-05-17 Add current PCB
    [juksautin.kicad_pcb, juksautin.sch]
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2021-05-19 enclosure: Make the front panel to fill the whole front side by making a 1mm step
    [juksautin.scad]
2021-05-24 Support 24VDC input
    [juksautin.kicad_pcb, juksautin.sch]
2021-05-28 pcb: Make the board two-layer instead of one
    [juksautin.kicad_pcb, juksautin.sch]
2021-05-31 Some final tweaks for the ordered PCB
    [juksautin.kicad_pcb]
2021-06-02 Add discrete Atmega32u4 board
    [juksautin.kicad_pcb, juksautin.sch]
2021-06-02 pcb: Rename K5 to K9 everywhere
    [juksautin.sch]
2021-06-03 pcb: Route everything Atmega board
    [juksautin.kicad_pcb, juksautin.sch]
2021-06-03 pcb: Rerouting and cleanup
    [juksautin.kicad_pcb]
2021-06-03 pcb: Make schema a bit more readable
    [juksautin.kicad_pcb, juksautin.sch]
2021-06-03 pcb: Replace LM2576 with Recom R-78E5.0 THT DC/DC converter
    [juksautin.kicad_pcb, juksautin.sch]
2021-06-04 Atmega328 based pcb layed out
    [juksautin.kicad_pcb, juksautin.sch]
2021-06-04 Add an indicator LED
    [juksautin.kicad_pcb, juksautin.sch]
2021-06-04 pcb: Replace IDC-6 connector with plain pins. The casing is 3D printed.
    [juksautin.kicad_pcb, juksautin.sch]
2021-06-04 pcb: Make it pass DRC test (clean courtyards
    [juksautin.kicad_pcb]
2021-06-07 enclosure: Make full-height dent
    [juksautin.scad]
2021-06-07 enclosure: Adjust dimensions
    [juksautin.scad]
2021-06-07 pcb: Random changes in Atmega32u4 board
    [juksautin.kicad_pcb]
2021-06-07 Add IDC connector instead of USB
    [juksautin.scad]
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2021-06-14 Count juksautus correctly. Optimize order to make it start measuring earlier.
    [juksautin.ino]
2021-06-15 enclosure: Make opening narrower because USBasp has narrow 6-pin plug
    [juksautin.scad]
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2021-06-15 avr: Use nice pin macros supporting pin defines, too
    Allows us to lift requirement to Arduino digitalWrite and pinMode
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2021-06-15 avr: Remove (almost all) traces of C++ and make it C99 compliant
    Serial is still there but we take it out soon.
2021-06-15 avr: Make it compile and work with CMake instead of Arduino IDE
2021-06-17 Schema and layout fixes after v0.9
    - Crystal Y1 symbol changed to 4-pin, affecting the wiring as well
    - Remove DC block capacitor C6, blocked RESET signal
    [juksautin.kicad_pcb, juksautin.sch]
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2021-06-19 avr: Fix receiver
    - Turn off receiver when reading the buffer and most importantly:
    return it back to normal in the end
    - Use non-hacky boolean to mark when a message is available
    [main.c]
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2021-06-19 avr: Reorganized serial comms to serial.c but I broke something
    This is not properly working at the moment. Needs debugging. It
    compiles, though.
    [main.c, serial.c]
2021-06-19 pcb: Remove old Arduino / Atmega32u4 based pcb cad files
    [juksautin.kicad_pcb, juksautin.sch]
2021-06-19 pcb: Move atmega328p files from pcb-atmega/ to pcb/
    [juksautin.kicad_pcb, juksautin.sch]
2021-06-20 avr: Add debug print of received frame to understand the tx/rx issue
    [main.c]
2021-06-20 avr: Make serial_tx_start internally atomic to avoid issues
    [serial.c]
2021-06-21 pcb: Add debug header for serial comm, reduce unique capacitor count by 1
    [juksautin.kicad_pcb, juksautin.sch]
2021-06-21 pcb: Remove reset pad (we have header anyway) and and RX pull-up
    RX pull-up seems to be required to keep RX HIGH during transmit phase
    when SP3485 is HI-Z.
    [juksautin.kicad_pcb, juksautin.sch]
2021-06-27 pcb: Some changes. Don't remember anymore.
    [juksautin.kicad_pcb, juksautin.sch]
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2021-06-27 pcb: Remove extra hole-trough from RX line
    [juksautin.kicad_pcb]
2021-06-27 avr: Meanwhile:x print everything we received on error
    [main.c]
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2021-06-29 avr: Fix problem with certain RS-485 hardware
    Some USB RS-485 adapters are not doing half duplex handover quickly
    enough. This adds a slight pause after last byte received.
    [main.c, serial.c]
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2021-07-03 avr: String formatting corrections
    [main.c]
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2021-07-03 avr: Add error LED read
    [main.c]
2021-07-03 avr: Use printf to print the error data as well
    [main.c]
2021-08-20 Improve double buffering by protecting the front buffer at all costs.
    If there's an overflow, error counter is increased and one frame is
    discarded.
    [main.c, serial.c]
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2021-08-20 avr: Important fix in timer comments The unit is not milliseconds!
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2021-08-22 avr: Minor fix: Change data type of a incoming char to uint8_t
    [serial.c]
2021-08-22 avr: Major serial rewrite. Hope I didn't break it. First part of #2
    Serial messages is no longer null terminated and the message's
    trailing newline is no longer suppressed. We need to replace (\r)\n
    with \0 to keep string functions working until we go all in to Modbus.
    Changed data types of buffers to uint8_t* and make the lengths uint8_t
    because in practice the buffers will never be larger than 255
    bytes. No more is practical anyway with a microcontroller with 2
    kilobytes of SRAM. Because of uint8_t pointers, occassional type casts
    are necessary to make it work with strcmp and friends.
    In case we regret making the length 8-bit, it should be safe to go for
    16 bits by changing lengths to ui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
    [main.c, serial.c]
2021-09-01 Added GPLv3 text and "GPLv3 or later" copyright header in source files
    Fixes #1
    [adc.c, main.c, serial.c]
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2021-09-02 avr: Fix VOLTAGE command to report the target voltage correctly
    It used to give always 0 because there was a divide by 1000 in the
    code. Now it still divides it, but uses float formatting.
    [main.c]
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2021-09-03 avr: Make serial transmitter binary safe. Closes #2
    This patch introduces serial_tx_line() which behaves similarily than
    earlier serial_tx_start() but verifies the string is NUL terminated
    and adds ellipsis if the string is too long.
    [main.c, serial.c]
2021-09-04 avr: Minor tweaks in error message formatting #10
    [main.c]
2021-09-04 avr: Improve serial line sending
    - Use > instead of .. for marking too long messages
    - Do not send messages which are not NUL terminated at all
    - Some tidying
    [serial.c]
2021-09-04 avr: Avoid having serial_tx_line() in every case #10
    [main.c]
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2021-09-07 avr: Register definition generator for Modbus #5
    [commands.tsv]
2021-09-08 avr cmd: Drop cmd_ prefix from the table for clarity #5
    [commands.tsv]
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2021-09-08 avr: Throw away current serial code and replace it with a parser #5
    NB! This removes all control logic instead of LED control!
    The parser has only only minimal set of supported functions, no read
    support yet.
    [commands.tsv]
2021-09-09 avr: Implement ASCII read support #5
    [commands.tsv]
2021-09-09 avr: Add LED read and improve comments #5
    [commands.tsv]
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2021-09-09 avr: Naming change, clock -> time to match the public interface #10
    [commands.tsv]
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2021-09-10 Add support for setting time and time zone info through ASCII #5
    [commands.tsv]
2021-09-10 avr: Add version command for ASCII protocol #5
    [commands.tsv]
2021-09-10 Make commands.tsv simpler by stripping repetitive prefixes
    [commands.tsv]
2021-09-11 avr: Collect highest value instead of an average for error LED #4
    [juksautin.c]
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2021-09-11 avr: Replace floating point mean calculator with a getter #17
    This function makes it easier to retrieve an individual value from an
    accumulator. It makes a copy, cleans the original and returns a
    copy. It's up to the caller to calculate the mean by the means
    necessary. :-)
    [juksautin.c]
2021-09-11 avr: Make accumulators to drop bits if they run full. Closes #18
    This patch defines a certain high water level mark for the accumulator
    when the least significant bits of both divident and divisor are
    thrown away to give more room. This of course affects the mean
    calculation but with so unnoticable amount.
    So it doesn't make a great difference in math frees the user from
    handling errors related to overflown counters.
    [juksautin.c]
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2021-09-12 avr: Add API for error LED and outside temperature reading
    [juksautin.c]
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2021-09-12 avr: Serial interface for reading target value and error LED #5
    [commands.tsv]
2021-09-12 avr: Add ASCII commands ffor reading K5, K9, and outside temperature #5
    [commands.tsv]
2021-09-12 avr: Store time zone and daylight savings data to EEPROM #19
    [commands.tsv]
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2021-09-13 avr: Remove the support for comma separated values
    The function was pretty but unnecessarily complicated. We don't have
    the need for writing multiple values at the same time and it's kind of
    against the spirit of Modbus.
    [commands.tsv]
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2021-09-13 avr: Detect if time string cut short
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2021-09-13 avr: Fix accumulator reader
    [juksautin.c]
2021-09-13 avr: Add getter for juksautus ratio
    [commands.tsv]
2021-09-18 avr: Move Modbus related types to a header #16
    This module doesn't depend on Modbus bus availability.
    [juksautin.c]
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2021-09-18 avr: Refactor the whole command binary interface
    This needs less wrappers for doing the same stuff. Little more type
    unsafe, though.
    [commands.tsv]
2021-09-19 avr: Add command "get now" for getting current time. Make register int32s
    Allows turning off date formatting easily and makes the getters and
    setters use the same format. I.e. if you get value with "get time" you
    could put the same value to "set time".
    Using cmd_print_now uses 2778 bytes of Flash and 114 bytes of SRAM so
    it's huge. But just removing the line from commands.tsv makes the link
    time optimization to take it away if not needed.
    [commands.tsv]
2021-09-19 avr: Add some type safety to commands.tsv
    When all the header files are included it detects type mismatches at
    compile time because of the conflicting types. This makes it easier to
    avoid catastrophic run-time function pointer type cast errors when
    filling in commands.tsv.
    [commands.tsv]
2021-09-19 avr: Add data type for string to make the command interface consistent
    [commands.tsv]
2021-09-19 avr: Replace cmd_print and cmd_scan in commands.tsv with a data type
    [commands.tsv]
2021-09-19 avr: Move non-juksautin functions to misc.c
    [commands.tsv]
2021-09-20 avr: Make the modbus registers adjacent #16
    [commands.tsv]
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2021-09-21 avr: Changes in the register table #16
    Disable the boolean register until we have support for it. This
    doesn't affect ASCII protocol but allows the project to compile.
    Make all the read-only registers input registers instead of holding
    registers.
    [commands.tsv]
2021-09-21 Use same object type abbreviations than in modbus_cli for clarity
    https://github.com/favalex/modbus-cli/blob/master/README.rst#access-syntax
    [commands.tsv]
2021-09-21 Make generator work with boolean modbus registers. Use dummy. #16
    Dummy register is added to command.tsv temporarily to aid in testing.
    [commands.tsv]
2021-09-25 juksutil: Do not crash in case of a directory
2021-09-25 juksutil: Remove unnecessary debug print and use correct data types
2021-09-26 juksutil: Replace device clock synchronization tool with a better
    Did a proper C implementation for clock sync, replacing the hacky
    script.
    [main.c]
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2021-09-30 juksutil: Better Modbus errors #10
    [main.c]
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2021-10-01 juksutil: Improve error message and make sure len is 0
    [main.c]
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2021-10-03 juksutil: For date to get better date parsing facility than libc
    The point is the parsing function is part of Gnulib which would be
    license compatible but too much work. It's better to just fork that
    command for this kind of seldom-used feature.
    [main.c]
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2023-10-25 juksutil: Shorten BREAK duration on platforms supporting it.
    [serial.c]

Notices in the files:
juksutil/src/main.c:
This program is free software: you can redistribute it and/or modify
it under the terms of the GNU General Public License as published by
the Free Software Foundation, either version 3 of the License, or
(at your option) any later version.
